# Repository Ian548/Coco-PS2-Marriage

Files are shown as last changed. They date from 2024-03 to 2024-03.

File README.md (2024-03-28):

I was feeling nostalgic recently and dug out my old Tandy Coco 2. It is in a bad way! Looking at the
date codes on the various chips inside it seems likely that this Coco was manufactured sometime in
1983 so it is not suprising that it is in poor condition. The case is badly yellowed and it has been
hacked at internally – not suprising as it waas made last century! After carefully removing the case top
I discovered that the RF modulator had presumably failed in the past and had been removed so the
video output now actually requires a monitor style device with composite video input instead of the old
TV set on channel 3 or 4. The memory had also been upgraded - piggyback style - using the Motorola
8040517 memory chip. Looking on the internet came up empty for the memory size of this chip,
however I believe it was a whole 16Kb device which likely doubled the original memory of the Coco
(WOW 32Kb RAM!!!).
Having found a monitor with a suitable composite video input I decided to fire up the Coco. This is
where the fun really started, only about half of the keys on the built in keyboard worked. After consulting the
internet again it appeared that the keyboard is a flex circuit design doubled over with crossover points in
the tracks that were shorted by pressing a key. The short should have been around 300 ohms or less so
I unplugged the keyboard from the main board and carried out continuity checks which changed every
time I tried them. Inspection of the plug part of the flex circuit revealed that of the 15 tracks the
majority were cracked. Tried the circuit pen on these tracks to try to restore the continuity but every
time I fixed one track another broke. The flex circuit is an acetate sheet which could not be soldered so
it appeared that I needed a new keyboard! Back to the internet but found nothing in my search and
being a bit of an electronic horder I didn’t want to just throw out the Coco so I would have to make a
newer keyboard do the job. I decided to use a PS2 keyboard for this as they are cheap and there is a
good supply of them – this is where the project started!!

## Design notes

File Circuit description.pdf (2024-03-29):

Project and Circuit Description

The original Coco2 keyboard is of a simple matrix design with 55 keys/functions and the Coco responded when a key was released – except the Shift key which was required to be pressed whenever a “shifted” function was required. Its key codes are unique being row and column. Even the PS2 keyboard uses serial communication thus some kind of code changer is required to to convert the serial codes of the PS2 keyboard¹
to emulate the matrix keyboard signals needed by the Coco.

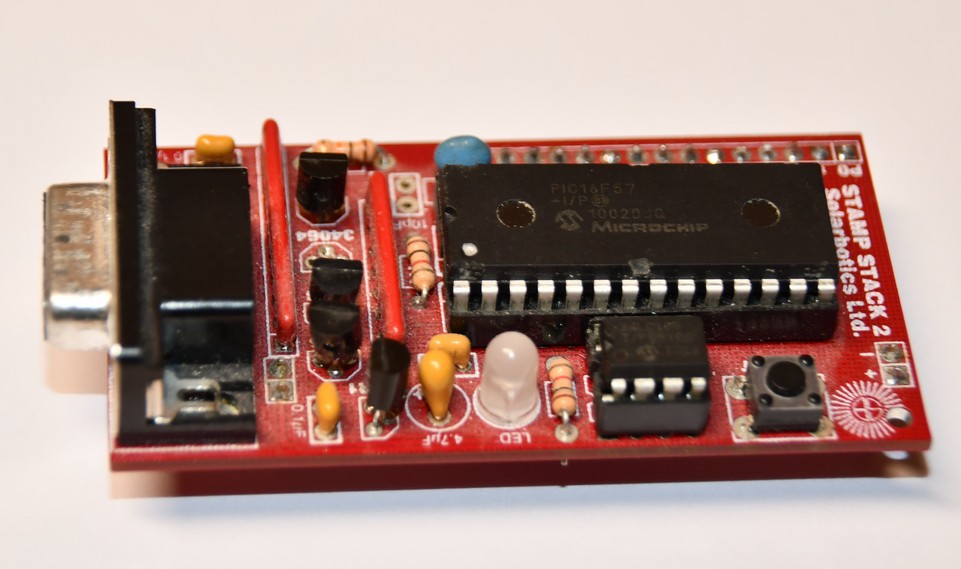
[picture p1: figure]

The ‘schematic.pdf’ file shows the circuit I designed to fit this requirement. The connector at the top of the diagram connects to a Parallax Stamp StackII which I programmed to do the code conversion. (The Stamp StackII I used was in my spare parts box and required a serial connection for programming.) My circuit board design has the Stamp Stack as a plug in piece.

The two connectors on the right of the circuit (see schematic.pdf) connect to the Coco keyboard connector .

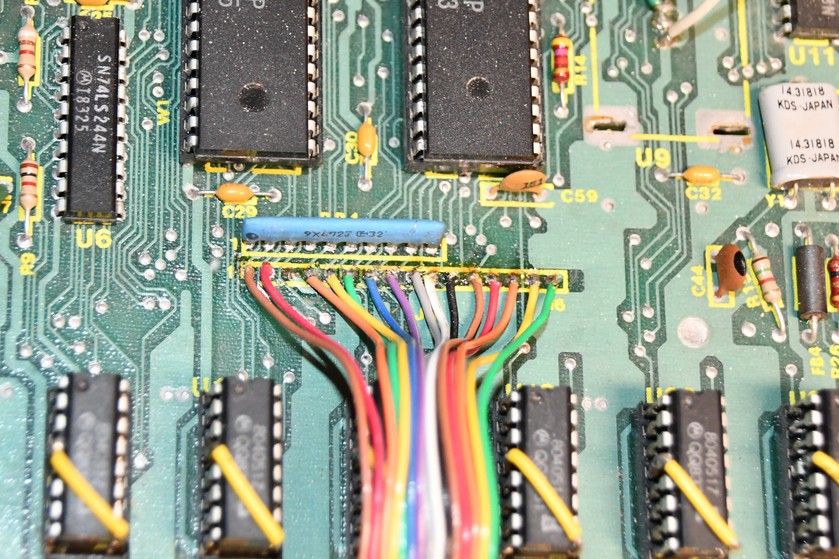
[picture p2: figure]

I removed this connector from the Coco main board (picture) and soldered wires directly to it. It was quite a tricky task to remove the connector without damaging the board. I used colour coded wires for pin identification with pin 1 being on the left (brown) in the picture. Note that pin 3 is missing on the connector. This identifies the ‘ROW’ connections.

The upper left connector is where the PS2 keyboard plugs in and below it is the +5Volt power connection which I linked in to the Coco power supply.

The six integrated circuits on the left of the diagram do the actual decoding of the PS2 scan codes and feed their output to the Stamp StackII as a 7 bit parallel word. The Stamp StackII program outputs two binary coded bytes to the circuitry on the right which emulates the old keyboard matrix.

1 Key codes found at HTTP://www.techtoys.com.hk/Downloads/Download/Microchip/PS2_driver/ScanCode.pdf

The Stamp StackII

Coco Main Board showing Connections

There are a few keys that do not match the PS2 keyboard or are not present ( clear, break etc.) and some that do not match up with today’s keyboard layout (Brackets key etc.). These

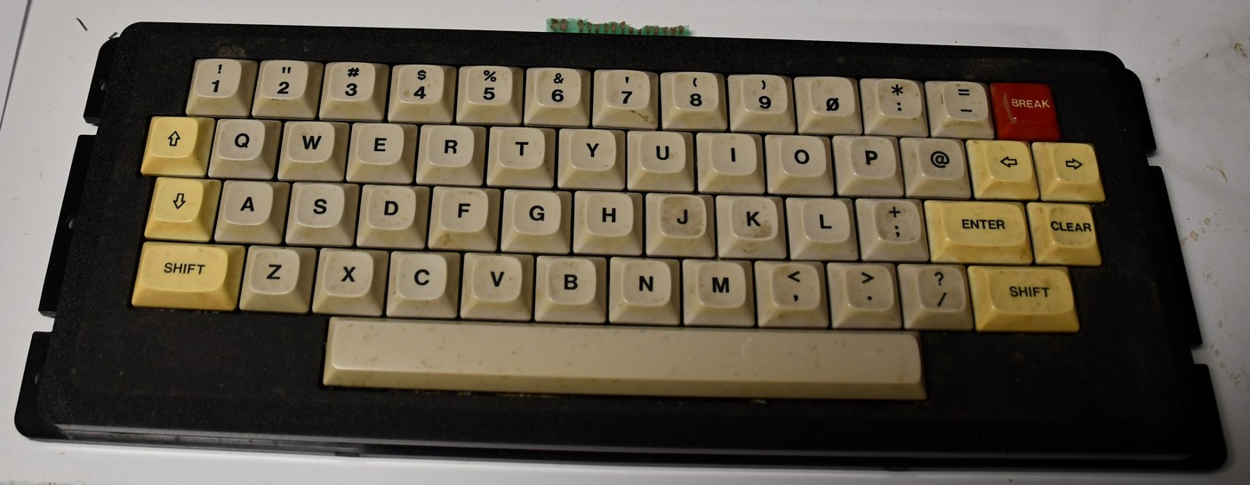
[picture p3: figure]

functions I arbitrarily assigned to various keys²
not used for other
purposes. They can be changed
in the Stamp StackII program by
reassigning the scan codes.

The coding process was fairly straight forward. Principally just a form of lookup table was required. The only wrinkles were the use of the Stamp Pin 3 to enable the row and column decoders and Pin 7 to enable the pulses to be output to the rows. Pin 15 was used for the shift function. Just a quick note here about operating systems. If you don’t use Windows as an operating system you will have a problem running the Parallax IDE³
software I didn’t try a Mac system but it won’t run in Ubuntu Linux. I used a Windows 10 tablet which also had a serial port for the Stamp as a bonus. My program is available here in the “akeyrowlookup.bs2” file

This project gave me a working replacement keyboard for my old Coco2. Lucky for me the parts – except for the circuit board itself – all came from my spares box and the final result is that my Coco2 can now be used for all its original functions albeit with more actual computing power in the new keyboard than in the Coco itself!

2 | The arbitrary keys chosen are:
| Break = Alt: Clear = Ctrl: @ = ]: : = [: ^ = Shift &: & = Shift ‘: “ = Shift(: Keys not available on the Coco are not
| coded.
3 | IDE software can be downloaded from HTTP://www.parallax.com/package/basic-stamp-editor-software-for-windows/

My Tandy Coco2 defunct Keyboard

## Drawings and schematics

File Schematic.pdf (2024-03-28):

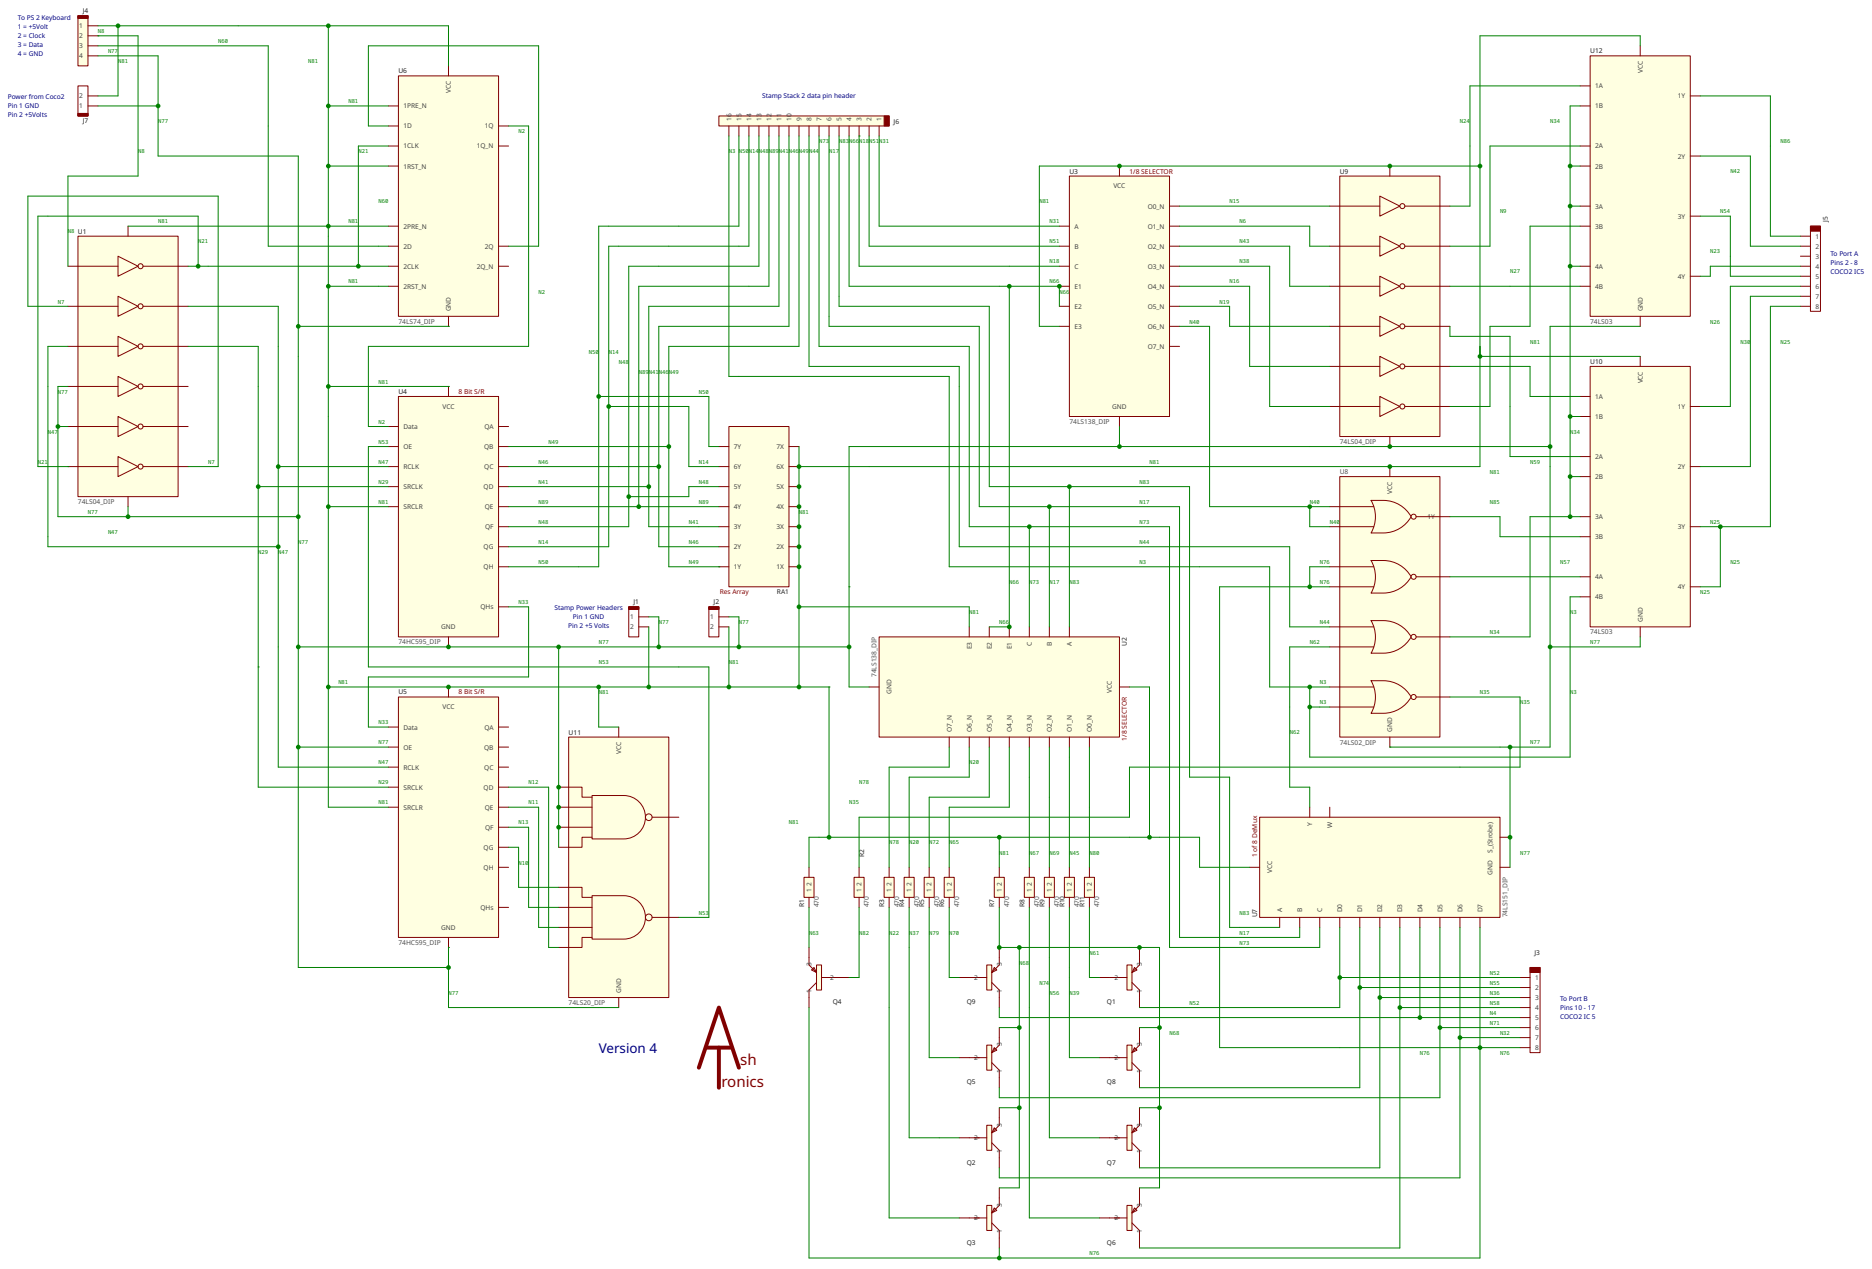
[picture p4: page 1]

N 5 5
N 3 6
N 5 8
N 4
